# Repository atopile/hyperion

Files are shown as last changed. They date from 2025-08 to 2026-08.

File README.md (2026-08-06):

<p align="center">
  Hyperion
</p>

<p align="center">Insanely bright modular LED display</p>

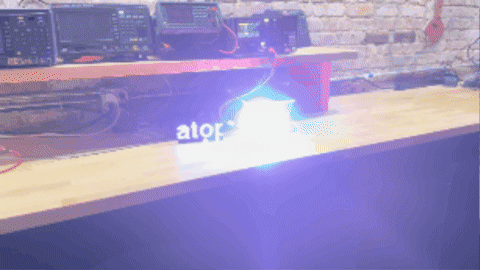
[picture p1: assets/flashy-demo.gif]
Flashy demo


### *** IN DEVELOPMENT ***
Project is currently in development and may not compile with latest compiler.

### Why

Current LED matrix displays are underwhelming: low brightness, low dynamic range, and washed‑out visuals in real venues. Hyperion flips that on its head with ridiculous luminance, high refresh, and a visual language that holds up in fog, dark, and daylight spill.

### Highlights

- **Blinding brightness**: designed to punch through haze and stage lighting
- **High refresh**: > 500 Hz target for artifact‑free motion and strobes
- **Chunky pixels**: 4 LEDs per pixel, **15 mm pitch** for bold geometry
- **Modular**: building full **420 × 420 mm** panels (limited by JLC assembly)
- **Controls**: video stream input (WIP) + DMX for audio‑sync (planned)

### Status

- We’ve built an initial coupon: **60 × 60 mm**, peak measured draw ~ **42 W**
- Driver: Macroblock **MBI5043** current sink
- Power rails: LED 5–17 V, logic 5 V / 3.3 V
- Hardware source is being reconstructed in ato v2 from the pixel upward.
  Pixel, pixel-row, cluster, and cluster-row qualification builds are present;
  the dual-row, controller, and complete panel hierarchy remain in progress.

### Hardware source

The root `ato.yaml` is the ato-v2 project. Physical parts resolve through the
v2 library server rather than vendored component assets. The migration is
validated bottom-up using the individual build targets before each layer is
connected into the full panel.

The shared active-low snake-data enable boundary is modeled separately in
`modules/snake_enable_distribution.ato`: one 3.3 V-to-5 V translator drives
seven 5 V-referenced NC7SZ125 enable inputs and defaults them disabled with a
pull-up.

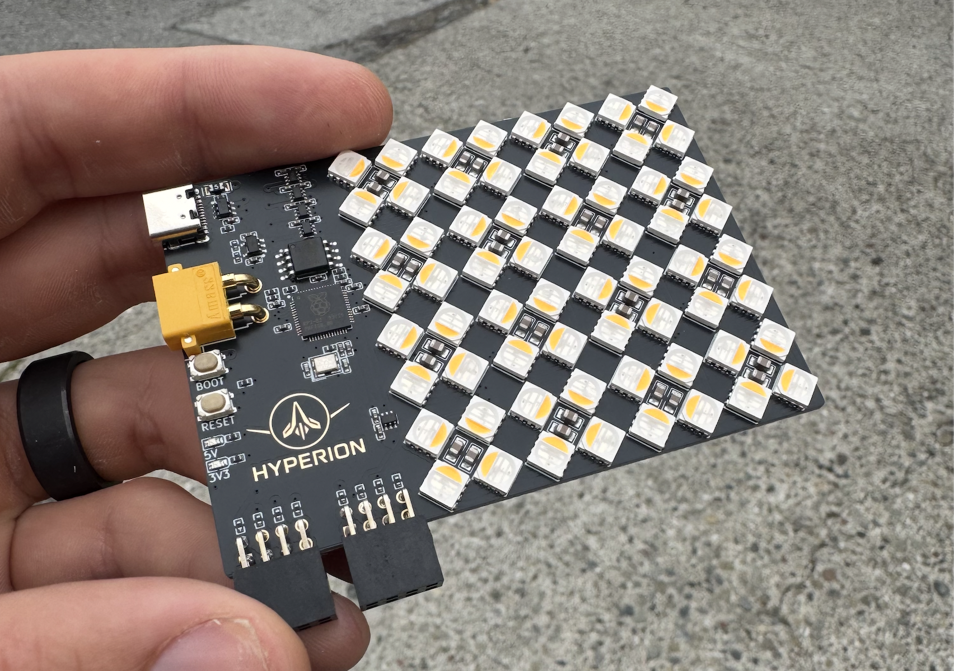
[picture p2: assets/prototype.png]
Prototype coupon


### Pixel geometry

- **Pitch**: 15 mm → ~66 px/m in each axis → ~4,444 px/m²
- **LEDs per pixel**: 4 (RGBW cluster) → ~17,776 LEDs/m²
- **Look**: deliberately low‑density, high‑punch “big voxel” aesthetic

### How bright is it? A back‑of‑the‑napkin estimate

- Coupon area A = 60 mm × 60 mm = **0.0036 m²**
- Peak power P ≈ **42 W**
- If LED efficacy η ≈ **60–100 lm/W** (RGBW mix, conservative):
  - Luminous exitance M ≈ P·η/A ≈ 0.94–1.17 × 10⁶ lm/m²
  - Luminance L ≈ M/π ≈ **220k–370k nits**
- Compared to MacBook Pro (XDR): typical SDR ~500 nits; HDR sustained ~1,000 nits; peak ~1,600 nits. Hyperion coupon (est.): **~140×–700× brighter** per unit area.
  - Peak power assumes ~1% duty cycle for bright strobe effects or fractional‑panel use; not continuous.

Note: 42 W on 0.0036 m² implies ~11.7 kW/m² at full blast. Scaled to a **3 × 2 m** panel: ~**70–75 kW** peak. This is a thermal and power‑distribution thought experiment, not a duty‑cycle recommendation.

### Light as an underexplored rave medium

Light isn’t just illumination; it’s a volumetric instrument. Hyperion treats photons like sound—sculpted in space, time, and intensity—to cut through haze and occupy the room, not just the wall.

- Spatial volume: beams and voxels that read in fog, from meters away
- Temporal punch: sub‑ms strobes and decay envelopes, not just fades
- Materiality: bold pixels and high luminance over fine‑pitch “screens”
- Emergence: interference, moiré, and wavefronts that breathe with the music

<p align="center">
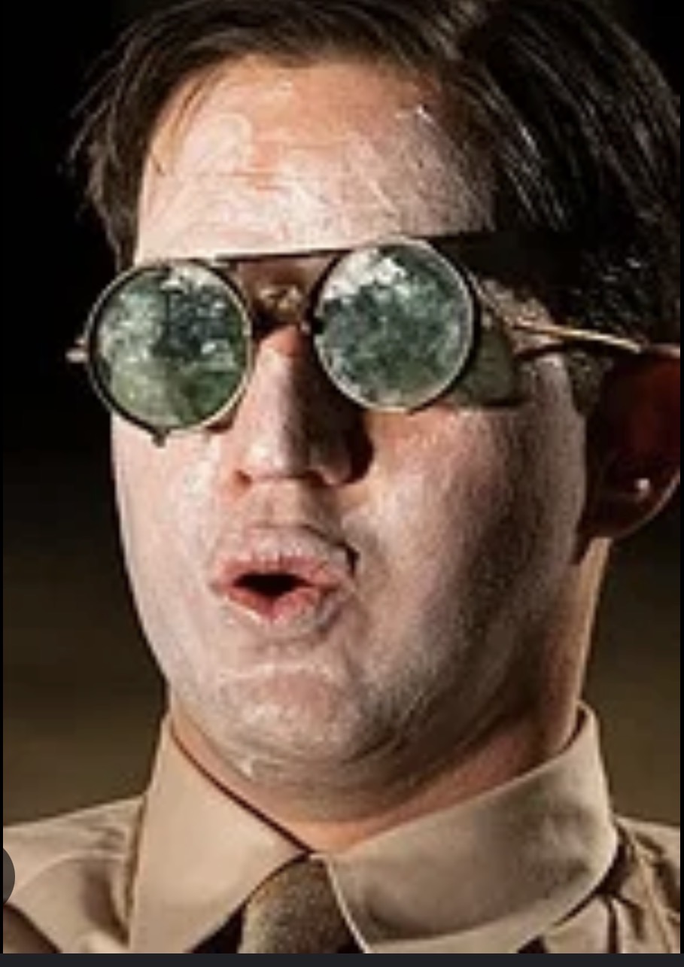
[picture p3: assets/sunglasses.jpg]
Bring sunglasses
  
</p>

### Roadmap

- Assemble first **420 × 420 mm** panels
- Ingest **video streams** (software pipeline WIP)
- **DMX** input for lighting desk sync and audio‑reactive modes
- Thermal, PSU, and duty‑cycle constraints for safe operation
- Thermal/power R&D: explore bulk energy storage (caps/supercaps) for strobe transients and peak handling
- Distributed temperature sensing across panels (NTC grid or digital sensors) for thermal maps and throttling

<p align="center">
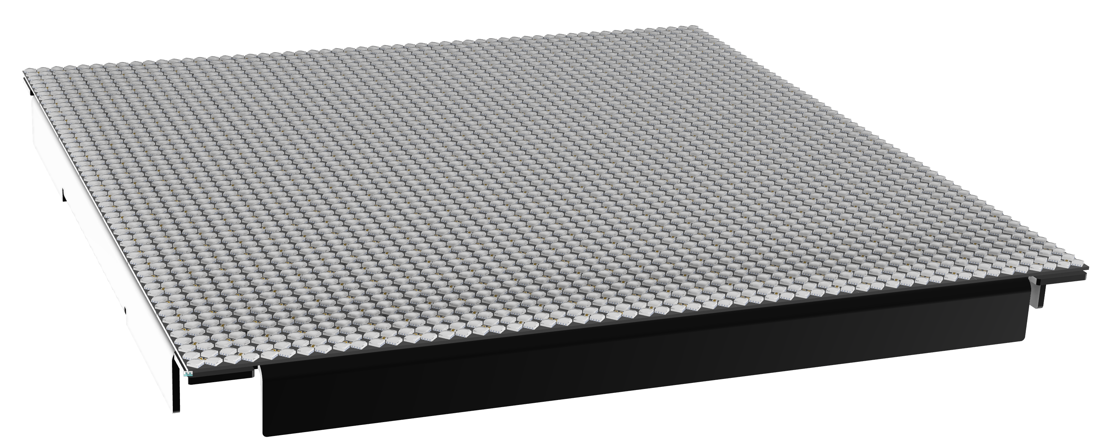
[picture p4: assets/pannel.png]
  
</p>

<p align="center">
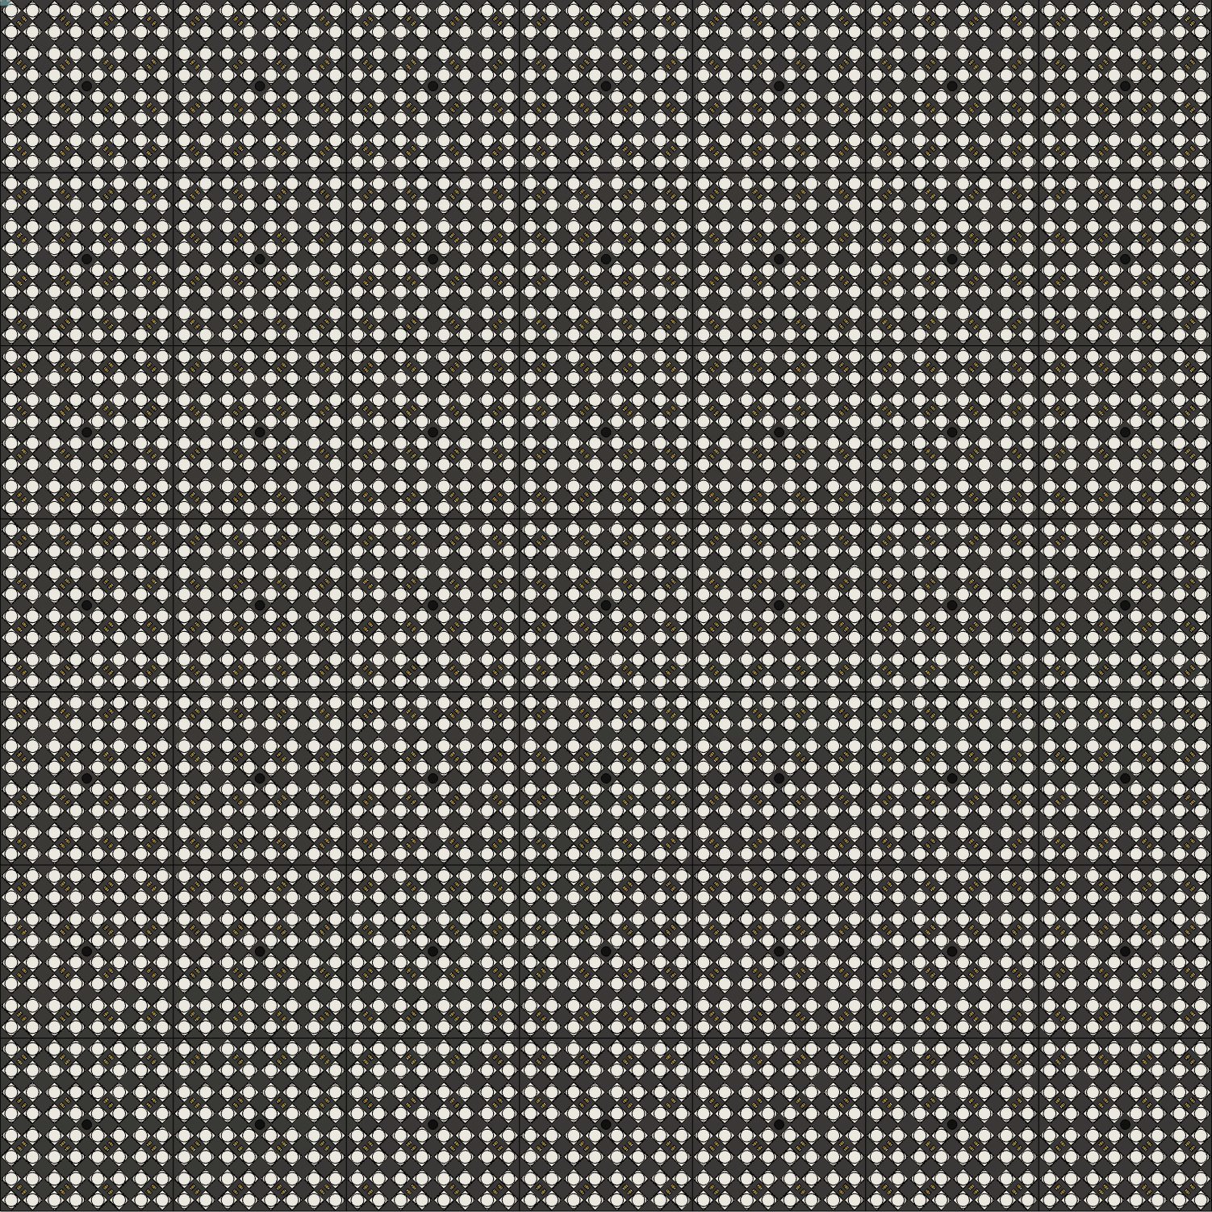
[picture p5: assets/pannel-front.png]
  
</p>

### License

MIT

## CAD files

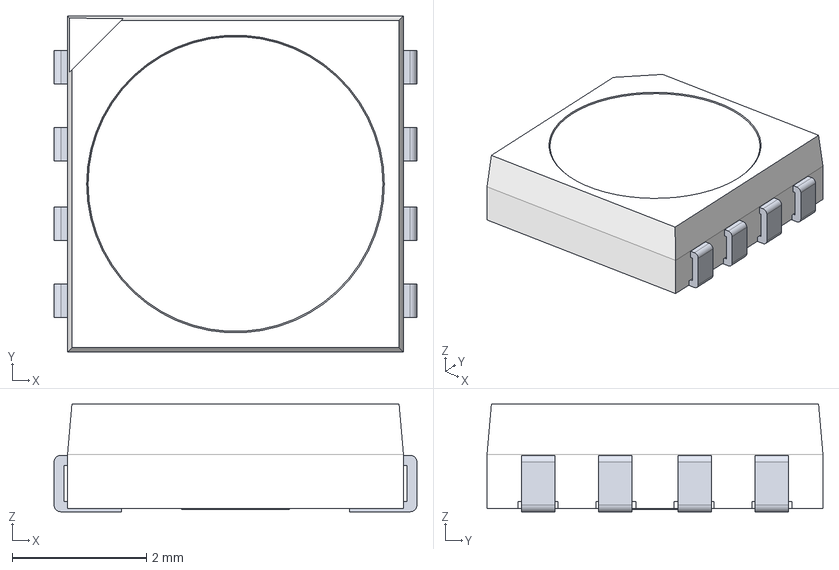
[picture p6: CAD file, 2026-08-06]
layouts/cluster/cluster.pcb.hl/3d_models/HONGLITRONIC_HL_5050RGBW_S1_A27/HONGLITRONIC_HL_5050RGBW_S1_A27.3dmodel.step
5.40 x 5.00 x 1.60 mm

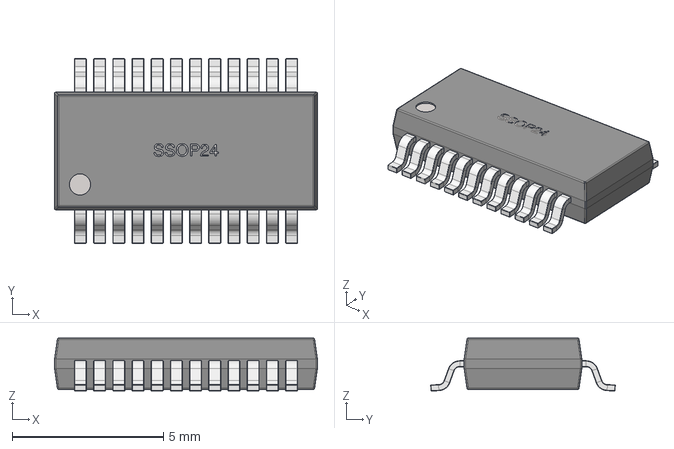
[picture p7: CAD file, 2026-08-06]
layouts/cluster/cluster.pcb.hl/3d_models/MBI_MBI5043GP_A/MBI_MBI5043GP_A.3dmodel.step
8.70 x 6.11 x 1.75 mm

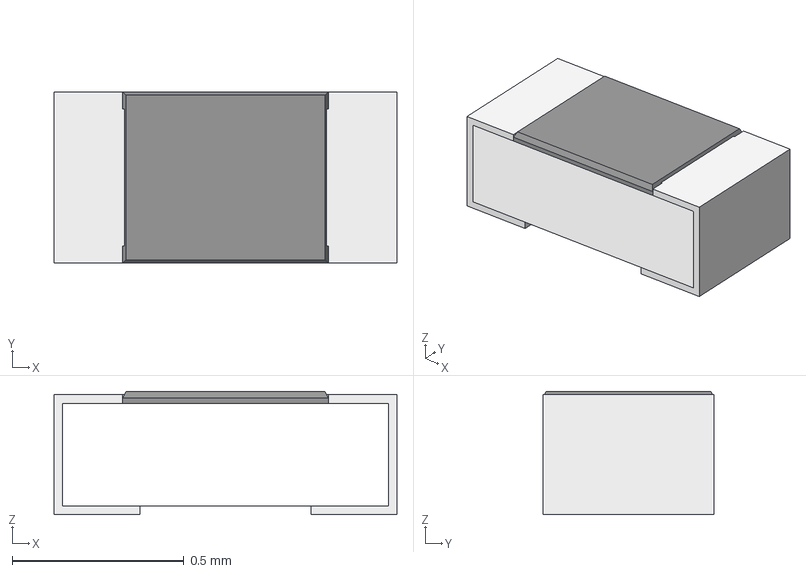
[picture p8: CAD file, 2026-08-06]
layouts/cluster/cluster.pcb.hl/3d_models/RALEC_RTT023090FTH/RALEC_RTT023090FTH.3dmodel.step
1.00 x 0.5 x 0.36 mm

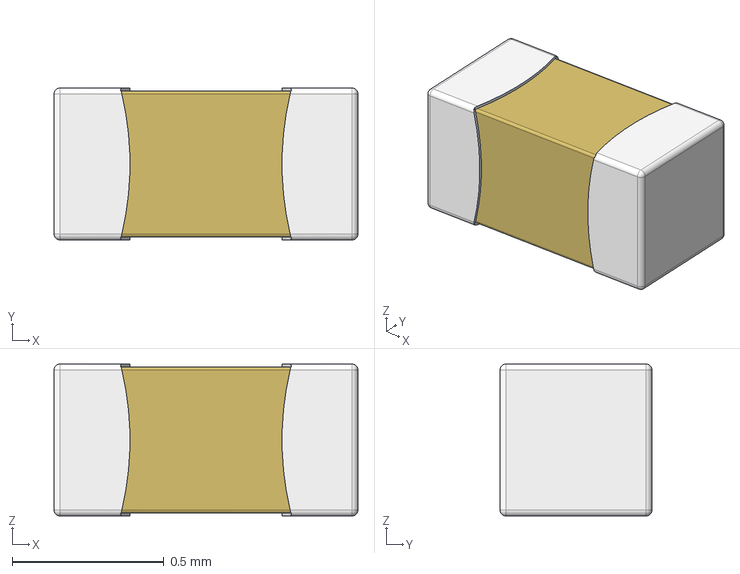
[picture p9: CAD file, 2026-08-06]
layouts/cluster/cluster.pcb.hl/3d_models/Samsung_Electro_Mechanics_CL05B104KO5NNNC/Samsung_Electro_Mechanics_CL05B104KO5NNNC.3dmodel.step
1.00 x 0.5 x 0.5 mm

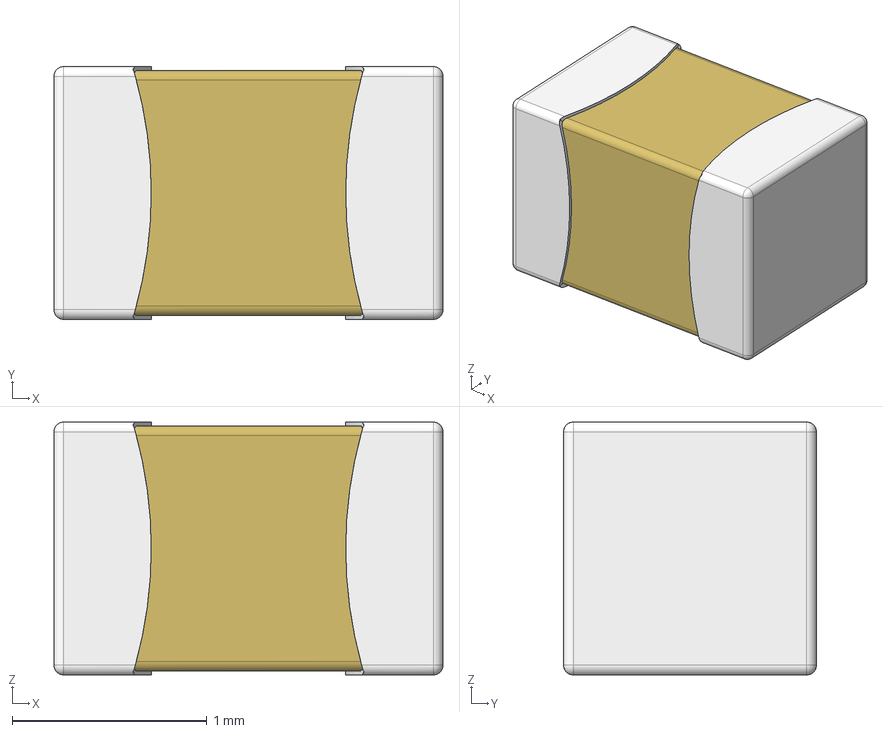
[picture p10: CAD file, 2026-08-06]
layouts/cluster/cluster.pcb.hl/3d_models/Samsung_Electro_Mechanics_CL21A106KAYNNNE/Samsung_Electro_Mechanics_CL21A106KAYNNNE.3dmodel.step
2.00 x 1.30 x 1.30 mm

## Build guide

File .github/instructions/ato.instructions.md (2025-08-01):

---
description: ato is a declarative DSL to design electronics (PCBs) with.
applyTo: *.ato, ato.yaml
---

ato is a declarative DSL to design electronics (PCBs) with.
It is part of the atopile project.
Atopile is run by the vscode/cursor/windsurf extension.
The CLI (which is invoked by the extension) actually builds the project.

# Not available in ato

- if statements
- while loops
- functions (calls or definitions)
- classes
- objects
- exceptions
- generators

# Ato Syntax

ato sytax is heavily inspired by Python, but fully declarative.
ato thus has no procedural code, and no side effects.

## Examples of syntax

```ato
#pragma text
#pragma func("X")
# enable for loop syntax feature:
#pragma experiment("FOR_LOOP)

# --- Imports ---
# Standard import (newline terminated)
import ModuleName

# Import with multiple modules (newline terminated)
import Module1, Module2.Submodule

# Import from a specific file/source (newline terminated)
from "path/to/source.ato" import SpecificModule

# Multiple imports on one line (semicolon separated)
import AnotherModule; from "another/source.ato" import AnotherSpecific

# Deprecated import form (newline terminated)
# TODO: remove when unsupported
import DeprecatedModule from "other/source.ato"

# --- Top-level Definitions and Statements ---

pass
pass;

"docstring-like statement"
"docstring-like statement";

top_level_var = 123

# Compound statement
pass; another_var = 456; "another docstring"

# Block definitions
component MyComponent:
    # Simple statement inside block (newline terminated)
    pass

    # Multiple simple statements on one line (semicolon separated)
    pass; internal_flag = True

module AnotherBaseModule:
    pin base_pin
    base_param = 10

interface MyInterface:
    pin io

module DemoModule from AnotherBaseModule:
    # --- Declarations ---
    pin p1              # Pin declaration with name
    pin 1               # Pin declaration with number
    pin "GND"           # Pin declaration with string
    signal my_signal    # Signal definition
    a_field: AnotherBaseModule      # Field declaration with type hint

    # --- Assignments ---
    # Newline terminated:
    internal_variable = 123

    # Semicolon separated on one line:
    var_a = 1; var_b = "string"

    # Cumulative assignment (+=, -=) - Newline terminated
    value = 1
    value += 1; value -= 1

    # Set assignment (|=, &=) - Newline terminated
    flags |= 1; flags &= 2

    # --- Connections ---
    p1 ~ base_pin
    mif ~> bridge
    mif ~> bridge ~> bridge
    mif ~> bridge ~> bridge ~> mif
    bridge ~> mif
    mif <~ bridge
    mif <~ bridge <~ bridge
    mif <~ bridge <~ bridge <~ mif
    bridge <~ mif

    # Semicolon separated on one line:
    p_multi1 ~ my_signal; p_multi2 ~ sig_multi1

    # --- Retyping ---
    instance.x -> AnotherBaseModule

    # --- Instantiation ---
    instance = new MyComponent
    container = new MyComponent[10]
    templated_instance_a = new MyComponent
    templated_instance_b = new MyComponent<int_=1>
    templated_instance_c = new MyComponent<float_=2.5>
    templated_instance_d = new MyComponent<string_="hello">
    templated_instance_e = new MyComponent<int_=1, float_=2.5, string_="hello">
    templated_instance_f = new MyComponent<int_=1, float_=2.5, string_="hello", bool_=True>

    # Semicolon separated instantiations (via assignment):
    inst_a = new MyComponent; inst_b = new AnotherBaseModule

    # --- Traits ---
    trait trait_name
    trait trait_name<int_=1>
    trait trait_name<float_=2.5>
    trait trait_name<string_="hello">
    trait trait_name<bool_=True>
    trait trait_name::constructor
    trait trait_name::constructor<int_=1>

    # Semicolon separated on one line:
    trait TraitA; trait TraitB::constructor; trait TraitC<arg_=1>

    # --- Assertions ---
    assert x > 5V
    assert x < 10V
    assert 5V < x < 10V
    assert x >= 5V
    assert x <= 10V
    assert current within 1A +/- 10mA
    assert voltage within 1V +/- 10%
    assert resistance is 1kohm to 1.1kohm

    # Semicolon separated on one line:
    assert x is 1V; assert another_param is 2V

    # --- Loops ---
    for item in container:
        item ~ p1

    # For loop iterating over a slice
    for item in container[0:4]:
        pass
        item.value = 1; pass

    # For loop iterating over a list literal of field references
    for ref in [p1, x.1, x.GND]:
        pass

    # --- References and Indexing ---
    # Reference with array index assignment
    array_element = container[3]

    # --- Literals and Expressions ---
    # Integer
    int_val = 100
    neg_int_val = -50
    hex_val = 0xF1
    bin_val = 0b10
    oct_val = 0o10
    # Float
    float_val = 3.14
    # Physical quantities
    voltage: V = 5V
    resistance: ohm = 10kohm
    capacitance: F = 100nF
    # Bilateral tolerance
    tolerance_val = 1kohm +/- 10%
    tolerance_abs = 5V +/- 500mV
    tolerance_explicit_unit = 10A +/- 1A
    # Bounded quantity (range)
    voltage_range = 3V to 3.6V
    # Boolean
    is_enabled = True
    is_active = False
    # String
    message = "Hello inside module"

    # Arithmetic expressions
    sum_val = 1 + 2
    diff_val = 10 - 3ohm
    prod_val = 5 * 2mA
    div_val = 10V / 2kohm # Results in current
    power_val = 2**3
    complex_expr = (5 + 3) * 2 - 1
    flag_check = state | MASK_VALUE

    # Comparisons
    assert voltage within voltage_range
    assert length <= 5mm
    assert height >= 2mm

# --- Multi-line variations ---
pass; nested_var=1; another=2

complex_assignment = (
    voltage + resistance
    * capacitance
)

```

## G4 Grammar

```g4
parser grammar AtoParser;

options {
	superClass = AtoParserBase;
	tokenVocab = AtoLexer;
}

file_input: (NEWLINE | stmt)* EOF;

pragma_stmt: PRAGMA;

stmt: simple_stmts | compound_stmt | pragma_stmt;
simple_stmts:
	simple_stmt (SEMI_COLON simple_stmt)* SEMI_COLON? NEWLINE;
simple_stmt:
	import_stmt
	| dep_import_stmt
	| assign_stmt
	| cum_assign_stmt
	| set_assign_stmt
	| connect_stmt
	| directed_connect_stmt
	| retype_stmt
	| pin_declaration
	| signaldef_stmt
	| assert_stmt
	| declaration_stmt
	| string_stmt
	| pass_stmt
	| trait_stmt;

compound_stmt: blockdef | for_stmt;

blockdef: blocktype name blockdef_super? COLON block;
// TODO @v0.4 consider ()
blockdef_super: FROM type_reference;
// TODO @v0.4 consider removing component (or more explicit code-as-data)
blocktype: (COMPONENT | MODULE | INTERFACE);
block: simple_stmts | NEWLINE INDENT stmt+ DEDENT;

// TODO: @v0.4 remove the deprecated import form
dep_import_stmt: IMPORT type_reference FROM string;
import_stmt: (FROM string)? IMPORT type_reference (
		COMMA type_reference
	)*;

declaration_stmt: field_reference type_info;
field_reference_or_declaration:
	field_reference
	| declaration_stmt;
assign_stmt: field_reference_or_declaration '=' assignable;
cum_assign_stmt:
	field_reference_or_declaration cum_operator cum_assignable;
// TODO: consider sets cum operator
set_assign_stmt:
	field_reference_or_declaration (OR_ASSIGN | AND_ASSIGN) cum_assignable;
cum_operator: ADD_ASSIGN | SUB_ASSIGN;
cum_assignable: literal_physical | arithmetic_expression;

assignable:
	string
	| new_stmt
	| literal_physical
	| arithmetic_expression
	| boolean_;

retype_stmt: field_reference ARROW type_reference;

directed_connect_stmt
	: bridgeable ((SPERM | LSPERM) bridgeable)+; // only one type of SPERM per stmt allowed. both here for better error messages
connect_stmt: mif WIRE mif;
bridgeable: connectable;
mif: connectable;
connectable: field_reference | signaldef_stmt | pindef_stmt;

signaldef_stmt: SIGNAL name;
pindef_stmt: pin_stmt;
pin_declaration: pin_stmt;
pin_stmt: PIN (name | number_hint_natural | string);

new_stmt: NEW type_reference ('[' new_count ']')? template?;
new_count: number_hint_natural;

string_stmt:
	string; // the unbound string is a statement used to add doc-strings

pass_stmt:
	PASS; // the unbound string is a statement used to add doc-strings

list_literal_of_field_references:
	'[' (field_reference (COMMA field_reference)* COMMA?)? ']';

iterable_references:
	field_reference slice?
	| list_literal_of_field_references;

for_stmt: FOR name IN iterable_references COLON block;

assert_stmt: ASSERT comparison;

trait_stmt
	: TRAIT type_reference (DOUBLE_COLON constructor)? template?; // TODO: move namespacing to type_reference
constructor: name;
template: '<' (template_arg (COMMA template_arg)* COMMA?)? '>';
template_arg: name ASSIGN literal;

// Comparison operators --------------------
comparison: arithmetic_expression compare_op_pair+;

compare_op_pair:
	lt_arithmetic_or
	| gt_arithmetic_or
	| lt_eq_arithmetic_or
	| gt_eq_arithmetic_or
	| in_arithmetic_or
	| is_arithmetic_or;

lt_arithmetic_or: LESS_THAN arithmetic_expression;
gt_arithmetic_or: GREATER_THAN arithmetic_expression;
lt_eq_arithmetic_or: LT_EQ arithmetic_expression;
gt_eq_arithmetic_or: GT_EQ arithmetic_expression;
in_arithmetic_or: WITHIN arithmetic_expression;
is_arithmetic_or: IS arithmetic_expression;

// Arithmetic operators --------------------

arithmetic_expression:
	arithmetic_expression (OR_OP | AND_OP) sum
	| sum;

sum: sum (PLUS | MINUS) term | term;

term: term (STAR | DIV) power | power;

power: functional (POWER functional)?;

functional: bound | name '(' bound+ ')';

bound: atom;

// Primary elements ----------------

slice:
	'[' (slice_start? COLON slice_stop? (COLON slice_step?)?)? ']'
	// else [::step] wouldn't match
	| '[' ( DOUBLE_COLON slice_step?) ']';
slice_start: number_hint_integer;
slice_stop: number_hint_integer;
slice_step: number_hint_integer;

atom: field_reference | literal_physical | arithmetic_group;

arithmetic_group: '(' arithmetic_expression ')';

literal_physical:
	bound_quantity
	| bilateral_quantity
	| quantity;

bound_quantity: quantity TO quantity;
bilateral_quantity: quantity PLUS_OR_MINUS bilateral_tolerance;
quantity: number name?;
bilateral_tolerance: number_signless (PERCENT | name)?;

key: number_hint_integer;
array_index: '[' key ']';

// backwards compatibility for A.1
pin_reference_end: DOT number_hint_natural;
field_reference_part: name array_index?;
field_reference:
	field_reference_part (DOT field_reference_part)* pin_reference_end?;
type_reference: name (DOT name)*;
// TODO better unit
unit: name;
type_info: COLON unit;
name: NAME;

// Literals
literal: string | boolean_ | number;

string: STRING;
boolean_: TRUE | FALSE;
number_hint_natural: number_signless;
number_hint_integer: number;
number: (PLUS | MINUS)? number_signless;
number_signless: NUMBER;
```

# Most used library modules/interfaces (api of them)

```ato
interface Electrical:
    pass

interface ElectricPower:
    hv = new Electrical
    lv = new Electrical

module Resistor:
    resistance: ohm
    max_power: W
    max_voltage: V
    unnamed = new Electrical[2]

module Capacitor:
    capacitance: F
    max_voltage: V
    unnamed = new Electrical[2]

interface I2C:
    scl = new ElectricLogic
    sda = new ElectricLogic
    frequency: Hz
    address: dimensionless

interface ElectricLogic:
    line = new Electrical
    reference = new ElectricPower
```

For the rest use the atopile MCP server 
- `get_library_interfaces` to list interfaces
- `get_library_modules` to list modules
- `inspect_library_module_or_interface` to inspect the code

# Ato language features

## experimental features

Enable with `#pragma experiment("BRIDGE_CONNECT")`
BRIDGE_CONNECT: enables `p1 ~> resistor ~> p2` syntax
FOR_LOOP: enables `for item in container: pass` syntax
TRAITS: enables `trait trait_name` syntax
MODULE_TEMPLATING: enables `new MyComponent<param=literal>` syntax

## modules, interfaces, parameters, traits

A block is either a module, interface or component.
Components are just modules for code-as-data.
Interfaces describe a connectable interface (e.g Electrical, ElectricPower, I2C, etc).
A module is a block that can be instantiated.
Think of it as the ato equivalent of a class.
Parameters are variables for numbers and they work with constraints.
E.g `resistance: ohm` is a parameter.
Constrain with `assert resistance within 10kohm +/- 10%`.
It's very important to use toleranced values for parameters.
If you constrain a resistor.resistance to 10kohm there won't be a single part found because that's a tolerance of 0%.

Traits mark a module to have some kind of functionality that can be used in other modules.
E.g `trait has_designator_prefix` is the way to mark a module to have a specific designator prefix that will be used in the designator field in the footprint.

## connecting

You can only connect interfaces of the same type.
`resistor0.unnamed[0] ~ resistor0.unnamed[0]` is the way to connect two resistors in series.
If a module has the `can_bridge` trait you can use the sperm operator `~>` to bridge the module.
`led.anode ~> resistor ~> power.hv` connects the anode in series with the resistor and then the resistor in series with the high voltage power supply.

## for loop syntax

`for item in container: pass` is the way to iterate over a container.

# Ato CLI

## How to run

You run ato commands through the MCP tool.

## Packages

Packages can be found on the ato registry.
To install a package you need to run `ato add <PACKAGE_NAME>`.
e.g `ato install atopile/addressable-leds`
And then can be imported with `from "atopile/addressable-leds/sk6805-ec20.ato" import SK6805_EC20_driver`.
And used like this:

```ato
module MyModule:
    led = new SK6805_EC20_driver
```

## Footprints & Part picking

Footprint selection is done through the part choice (`ato create part` auto-generates ato code for the part).
The `pin` keyword is used to build footprint pinmaps so avoid using it outside of `component` blocks.
Preferrably use `Electrical` interface for electrical interfaces.
A lot of times it's actually `ElectricLogic` for things like GPIOs etc or `ElectricPower` for power supplies.

Passive modules (Resistors, Capacitors) are picked automatically by the constraints on their parameters.
To constrain the package do e.g `package = "0402"`.
To explictly pick a part for a module use `lcsc = "<LCSC_PART_NUMBER>"`.

# Creating a package

Package generation process:

Review structure of other pacakges.

1. Create new Directory in 'packages/packages' with naming convention '<vendor>-<device>' eg 'adi-adau145x'
2. create an ato.yaml file in the new directory with the following content:

```yaml
requires-atopile: '^0.9.0'

paths:
    src: '.'
    layout: ./layouts

builds:
    default:
        entry: <device>.ato:<device>_driver
    example:
        entry: <device>.ato:Example
```

3. Create part using tool call 'search_and_install_jlcpcb_part'
4. Import the part into the <device>.ato file
5. Read the datasheet for the device
6. Find common interfaces in the part eg I2C, I2S, SPI, Power

7. Create interfaces and connect them

power interfaces:
power*<name> = new ElectricPower
power*<name>.required = True # If critical to the device
assert power\*<name>.voltage within <minimum*operating_voltage>V to <maximum_operating_voltage>V
power*<name>.vcc ~ <device>.<vcc pin>
power\_<name>.gnd ~ <device>.<gnd pin>

i2c interfaces:
i2c = new I2C
i2c.scl.line ~ <device>.<i2c scl pin>
i2c.sda.line ~ <device>.<i2c sda pin>

spi interfaces:
spi = new SPI
spi.sclk.line ~ <device>.<spi sclk pin>
spi.mosi.line ~ <device>.<spi mosi pin>
spi.miso.line ~ <device>.<spi miso pin>

8. Add decoupling capacitors

looking at the datasheet, determine the required decoupling capacitors

eg: 2x 100nF 0402:

power_3v3 = new ElectricPower

# Decoupling power_3v3

power_3v3_caps = new Capacitor[2]
for capacitor in power_3v3_caps:
capacitor.capacitance = 100nF +/- 20%
capacitor.package = "0402"
power_3v3.hv ~> capacitor ~> power_3v3.lv

9. If device has pin configurable i2c addresses

If format is: <n x fixed address bits><m x pin configured address bits>
use addressor module:

- Use `Addressor<address_bits=N>` where **N = number of address pins**.
- Connect each `address_lines[i].line` to the corresponding pin, and its `.reference` to a local power rail.
- Set `addressor.base` to the lowest possible address and `assert addressor.address is i2c.address`.

10. Create a README.md

# <Manufacturer> <Manufacturer part number> <Short description>

## Usage

```ato
<copy in example>

```

## Contributing

Contributions to this package are welcome via pull requests on the GitHub repository.

## License

This atopile package is provided under the [MIT License](https://opensource.org/license/mit/).

11. Connect high level interfaces directly in example:

eg:

i2c = new I2C
power = new ElectricPower
sensor = new Sensor

i2c ~ sensor.i2c
power ~ sensor.power_3v3

# Additional Notes & Gotchas (generic)

- Multi-rail devices (VDD / VDDIO, AVDD / DVDD, etc.)

    - Model separate `ElectricPower` interfaces for each rail (e.g. `power_core`, `power_io`).
    - Mark each `.required = True` if the device cannot function without it, and add voltage assertions per datasheet.

- Optional interfaces (SPI vs I²C)

    - If the device supports multiple buses, pick one for the initial driver. Leave unused bus pins as `ElectricLogic` lines or expose a second interface module later.

- Decoupling guidance

    - If the datasheet shows multiple caps, model the **minimum required** set so the build passes; you can refine values/packages later.

- File / directory layout recap
    - `<vendor>-<device>/` – package root
    - `ato.yaml` – build manifest (include `default` **and** `example` targets)
    - `<device>.ato` – driver + optional example module
    - `parts/<MANUFACTURER_PARTNO>/` – atomic part + footprint/symbol/step files

These tips should prevent common "footprint not found", "pin X missing", and build-time path errors when you add new devices.

# Vibe coding a project

If the user gives you high level description of the project, use the following guide:

# How LLMs can design electronics:

#1 Rule: USE THE TOOLS. If the tools dont work, dont freak out, you are probably using them wrong. Ask for help if you get stuck.

Top level design

1. Research available packages relevant to the user requests using 'find_packages'
2. Inspect promising packages using 'inspect_package'
3. Propose packages to use for project and architucture to user, revise if needed
4. Install needed packages using 'install_package'
5. Import packages into main file
6. Create instances of packages in main module

## Power

1. Review for each package the required voltage and current (current may not be provided, use judement if nessesary)
2. Determine the power rails that need to be generated and a suitable tollerance (typically ~3-5% is acceptable)
3. Determine the input power source, typically a battery, USB connector or other power connector (eg XT30) and install relevant package
4. Find suitable regulators:
   a) if input voltage > required voltage and current is low, use an LDO package
   b) if input voltage > required voltage and current is high, use buck converter
   c) if input votlage < required voltage, use a boost converter
   d) if input voltage can be both less than or greater than input voltage, use buck boost (eg battery powered device that needs 3v3)
5. If battery powered, add charger package

Typical power architucture example with LDO:

- USB input power
- Low current output (eg microcontroller)

from "atopile/ti-tlv75901/ti-tlv75901.ato" import TLV75901_driver
from "atopile/usb-connectors/usb-connectors.ato" import USBCConn

module App:

    # Rails
    power_5v = new Power
    power_3v3 = new Power

    # Components
    ldo = new TLV75901_driver
    usb_connector = new USBCConn

    # Connections
    usb_connector.power ~ power_vbus
    power_vbus ~> ldo ~> power_3v3

## Communicaions

1. Review packages required interfaces, typically i2c, spi or ElectricLogics
2. Find suitable pins on the controller, typically a microcontroller or Linux SOC
3. Connect interfaces eg micro.i2c[0] ~ sensor.i2c

## Development process notes

- After making changes, be sure to use 'build_project' to update the PCB
- Builds will often generate errors/warnings, these should be reviewed and fixed
- Prioritize pacakges from 'atopile' over other packages

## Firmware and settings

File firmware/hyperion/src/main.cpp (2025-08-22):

/**
 * RP2040 firmware for Macroblock MBI5043 16-channel LED driver chain
 *
 * Main application entry point
 */

#include "pico/stdlib.h"
#include "hardware/gpio.h"
#include "hardware/sync.h"
#include "hardware/structs/ioqspi.h"
#include "hardware/structs/sio.h"
#include <stdio.h>
#include "led_driver.h"
#include "animations.h"

// Boot button - connected to BOOTSEL via QSPI_SS
// Note: On most RP2040 boards, the BOOTSEL button pulls QSPI_SS low when pressed
#define BOOTSEL_BUTTON 1 // Use the SDK's BOOTSEL detection

// Animation modes
enum AnimationMode
{
  MODE_PULSING = 0,
  MODE_CHECKERBOARD,
  MODE_STROBE,
  MODE_ALTERNATING_STROBE,
  MODE_OFF,
  NUM_MODES
};

// Global state
volatile AnimationMode current_mode = MODE_ALTERNATING_STROBE;
volatile uint32_t last_button_time = 0;
const uint32_t DEBOUNCE_MS = 200; // Debounce time in milliseconds

// Check if BOOTSEL button is pressed
// This uses the recommended Pico SDK method
bool __no_inline_not_in_flash_func(is_bootsel_pressed)()
{
  const uint CS_PIN_INDEX = 1; // QSPI_SS

  // Must disable interrupts while reading button
  uint32_t flags = save_and_disable_interrupts();

  // Set chip select high to access the button
  hw_write_masked(&ioqspi_hw->io[CS_PIN_INDEX].ctrl,
                  GPIO_OVERRIDE_LOW << IO_QSPI_GPIO_QSPI_SS_CTRL_OUTOVER_LSB,
                  IO_QSPI_GPIO_QSPI_SS_CTRL_OUTOVER_BITS);

  // Read the button state (the button pulls the pin low when pressed)
  bool button_state = !(sio_hw->gpio_hi_in & (1u << CS_PIN_INDEX));

  // Restore chip select to normal SPI mode
  hw_write_masked(&ioqspi_hw->io[CS_PIN_INDEX].ctrl,
                  GPIO_OVERRIDE_NORMAL << IO_QSPI_GPIO_QSPI_SS_CTRL_OUTOVER_LSB,
                  IO_QSPI_GPIO_QSPI_SS_CTRL_OUTOVER_BITS);

  restore_interrupts(flags);

  return button_state;
}

// Check button and handle mode switching
void check_button()
{
  uint32_t now = to_ms_since_boot(get_absolute_time());

  // Check if enough time has passed for debouncing
  if (now - last_button_time < DEBOUNCE_MS)
  {
    return;
  }

  if (is_bootsel_pressed())
  {
    // Button is pressed, switch to next mode
    current_mode = (AnimationMode)((current_mode + 1) % NUM_MODES);
    last_button_time = now;

    // Print mode change
    switch (current_mode)
    {
    case MODE_PULSING:
      printf("Switched to: PULSING mode\n");
      break;
    case MODE_CHECKERBOARD:
      printf("Switched to: CHECKERBOARD mode\n");
      break;
    case MODE_STROBE:
      printf("Switched to: STROBE mode (174 BPM)\n");
      break;
    case MODE_OFF:
      printf("Switched to: OFF mode\n");
      break;
    }
  }
}

int main()
{
  // Arduino framework handles stdio initialization automatically
  sleep_ms(3000); // Wait for USB serial to connect

  printf("\n=== MBI5043 LED Matrix Controller ===\n");
  printf("  GPIO0 → SDI (Data to LEDs)\n");
  printf("  GPIO1 → DCLK (Data Clock)\n");
  printf("  GPIO2 → GCLK (Global Clock)\n");
  printf("  GPIO3 → LE (Latch)\n");
  printf("  GPIO4 ← SDO (Data from LEDs)\n");

  // Initialize LED driver
  printf("\nInitializing LED driver...\n");
  led_driver_init();

  // Main loop
  printf("Starting animation loop...\n");
  printf("Press BOOTSEL button to change animation mode\n");

  // Animation colors for checkerboard
  rgbw_color_t atopile_orange = {0x0, 0x15 / 4, 0x50 / 4, 0xF9 / 4};
  rgbw_color_t white = {0xFFFF / 4, 0, 0, 0};
  rgbw_color_t white_white = {0xFFFF, 0xFFFF, 0xFFFF, 0xFFFF}; // Full brightness WHITE_WHITE
  rgbw_color_t warm_white = {0xFFFF, 0, 0, 0};
  rgbw_color_t rgb_white = {0, 0xFFFF, 0xFFFF, 0xFFFF};
  rgbw_color_t blue = {0, 0xFFFF, 0, 0};
  rgbw_color_t green = {0, 0, 0xFFFF, 0};
  rgbw_color_t red = {0, 0, 0, 0xFFFF};

  while (true)
  {
    // Check button for mode change
    // check_button();

    // Run animation based on current mode
    switch (current_mode)
    {
    case MODE_PULSING:
      pulsing(0.2); // 0.2 Hz = 5 second cycle
      break;

    case MODE_CHECKERBOARD:
      checkerboard_flash(atopile_orange, white, 500);
      break;

    case MODE_STROBE:
      strobe(warm_white, 174.0f); // 174 BPM strobe
      break;

    case MODE_ALTERNATING_STROBE:
      strobe(warm_white, 174.0f / 2);
      strobe(white_white, 174.0f / 2);
      strobe(rgb_white, 174.0f / 2);
      strobe(red, 174.0f / 2);
      strobe(green, 174.0f / 2);
      strobe(blue, 174.0f / 2);
      break;

    case MODE_OFF:
      off();
      break;
    }
  }

  return 0;
}

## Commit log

2025-08-01 Init commit
    [R0603.STEP, demomatrix.kicad_pcb]
2025-08-01 pixel demos
    [LED-SMD_8P-L5.0-W5.0-P1.20_HL-5050RGBW-S1-A27.STEP, LED-SMD_8P-L5.0-W5.0-TL-FD.STEP, demomatrix.kicad_pcb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]
2025-08-01 Pixel15 & Cluster
    [cluster2x2.kicad_pcb, demomatrix.kicad_pcb, pixel10hl5050.kicad_pcb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]
2025-08-01 pixel10hl5050 routing
    [pixel10hl5050.kicad_pcb]
2025-08-02 pixel refactor
    [pixel10hl5050.kicad_pcb, pixel15hl5050.kicad_pcb]
2025-08-02 cluster with driver
    [C0402_L1.0-W0.5-H0.5.step, R0402_L1.0-W0.5-H0.4.step, R0603.STEP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]
2025-08-02 broken kicad file
    [cluster2x2.kicad_pcb]
2025-08-02 cluster fix up
    [C0805_L2.0-W1.3-H1.3.step, R0402_L1.0-W0.5-H0.4.step, cluster2x2.kicad_pcb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]
2025-08-03 shipped board
    [C0402_L1.0-W0.5-H0.5.step, R0402_L1.0-W0.5-H0.4.step, cluster2x2.kicad_pcb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]
2025-08-15 built this
    [R0402_L1.0-W0.5-H0.4.step, cluster2x2.kicad_pcb, cluster_test.kicad_pcb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]
2025-08-16 arduino -> pico-sdk
2025-08-16 toggle animation with button
2025-08-19 updating rp2040
    [C0402_L1.0-W0.5-H0.5.step, R0402_L1.0-W0.5-H0.4.step, cluster2x2.kicad_pcb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]
2025-08-22 tight layout
    [cluster2x2.kicad_pcb, demo_matrix2.kicad_pcb, pixel15hl5050.kicad_pcb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]
2025-08-30 cheat build 49 clusters no layout
    [pixel10hl5050.kicad_pcb, pixel10tc5050.kicad_pcb, pixel15hl5050.kicad_pcb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]
2025-09-12 switch to has_explicit_part for explicit picks
2026-08-06 feat: replace legacy hardware project with ato v2 migration (#3)
    Replace the obsolete ato v1 hardware tree with the bottom-up ato v2 Hyperion migration, including the shared 3.3 V-to-5 V snake-enable translator.
    [C0402_L1.0-W0.5-H0.5.step, C0805_L2.0-W1.3-H1.3.step, HONGLITRONIC_HL_5050RGBW_S1_A27.3dmodel.step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]
